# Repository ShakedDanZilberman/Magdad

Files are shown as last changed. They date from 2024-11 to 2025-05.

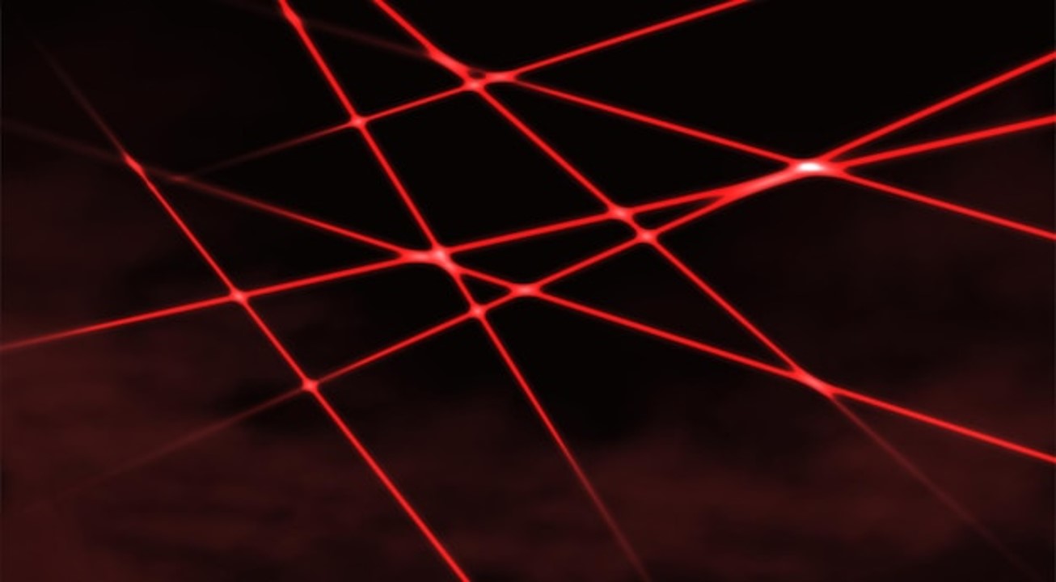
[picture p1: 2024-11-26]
management/requirements presentation/images/lasers.jpg

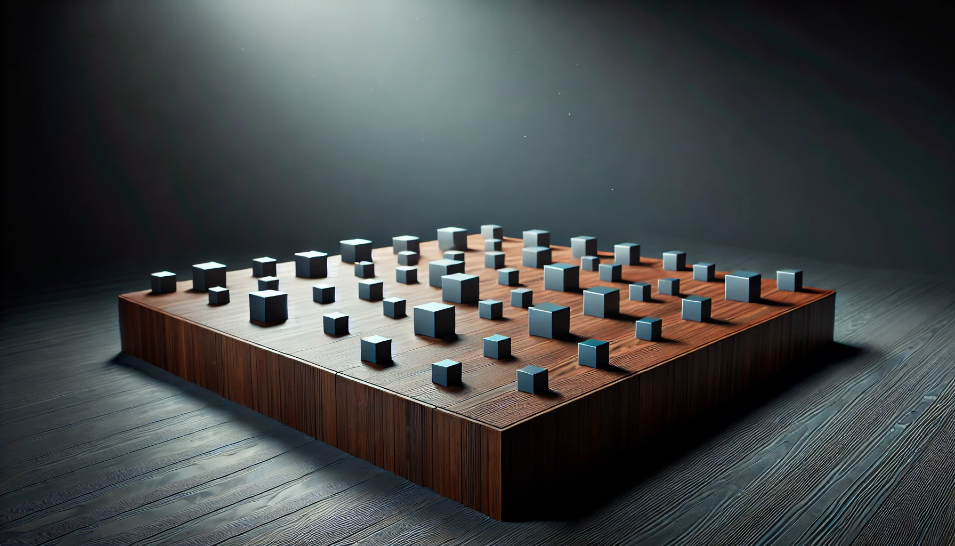
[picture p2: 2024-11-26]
management/requirements presentation/images/dalle image.png

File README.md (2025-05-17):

# Magdad
מגד"ד CounterStrike!
אפשר להגיד שזה מיני רואה יורה בחושך, מיתוג אחר זה לא רואה וכן יורה, יש כאלו שקראו לזה AimBot סטטי בחושך.
המטרה של הפרויקט שלנו היא להדגים יכולת של אחיזה בשטח עם אמצעים מינימליים, כאשר יכולת האש שלנו היא מוגבלת אבל יש הרבה מצלמות, אנחנו יכולים להגן על כל הגזרה בצורה המוצלחת ביותר ועדיין להיות אפקטיביים.

את מטרות אנחנו מזהים בעזרת מודל עיבוד תמונה שנקרא YOLO, לאחר מכן אנחנו משתמשים במנועי סטפר ותותחים שחילצנו מרובי ג'ל.

טבלת שיא כמות לשוניות פתוחות במחשב בנוגע למגדד:
|הערות|כמה|מי|
|---|---|---|
|אני היחיד שרושם?|46|יובל|
| |?|יהלי|
| |?|הוד|
| |?|איילה|
|חכו חכו|5|שקד|

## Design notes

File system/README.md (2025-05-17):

# CounterStrike
## Setup for Starting System (Laser+LIDAR)
1. Connect the 2 USB cables.
2. Open Arduino IDE.
3. Select Board > COM5 > Nano Arduino > OK.
4. File > Examples > Firmata > StandardFirmata.
5. Tools > Processor: "..." > "..." (Old Bootloader) > Upload.
6. Run `system/main.py`.

## To Calibrate the LIDAR Motion
1. Connect the laser pointer and LIDAR to the Arduino, as described above.
2. In `system/fit.py`, uncomment the line `# measure()` in `if __name__ == '__main__':`.
3. Turn off the light, darken the room, fix the system in place.
4. Run `system/fit.py`.
5. **COPY** the output to `system/fit.py` in the `MEASUREMENTS` variable. It will automatically propagate to the rest of the system.

## Errors and Fixes
1. `"pip is not recognized"`
להריץ
`python -m pip install ...`
אם לא עובד לנסות גם:
`py -m pip install ...`
`python3 -m pip install ...`
2. If `torch` fails, uninstall then install again.
3. if you get an error of "getargspec", change to getfullargspec in pyfirmata.

## 2025-05-16
We win.

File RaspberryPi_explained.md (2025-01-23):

## איך עובדים עם RPI בלי כל הכאב ראש ##
 - הRaspBerry PI (RPI) הוא לכל דבר ועניין מחשב קטן, שמריץ מערכת הפעלה מבוססת לינוקס.
 - אנחנו רוצים לכתוב קוד שבסופו של דבר הוא יריץ, מבלי להיות מחוברים אליו עם כבל. לכן אנחנו מתחברים אליו דרך פרוטוקול רשת SSH.
 - כדי להתחבר לRPI דרך הSSH אנחנו  אנחנו נתקין [קליינט SSH בשם PuTTY](https://www.putty.org/), נריץ את PuTTY ובחלון שנפתח נרשום ב Host Name את השם של הRPI שלנו ברשת raspberrypi.local, ונלחץ אנטר.
 - עכשיו אנחנו צריכים להתחבר לאיזשהו חשבון על הRPI:
   - שם משתמש: TeamEthel
   - סיסמה: grauer44 
 - עכשיו אנחנו בטרמינל של הRPI שלנו, יש!
 - אם אנחנו רוצים לראות גם את המסך, נשתמש בפרוטוקול VNC, נתקין [קליינט VNC בשם TigerVNC](https://tigervnc.org/), ובאופן דומה, נתחבר.
 - איך כותבים קוד? אפשר לכתוב ישירות בRPI, אפשר במחשב ואז להעביר קבצים אחד אחד.
 - אפשר לכתוב קוד דרך VS CODE על המחשב האישי בזמן שעורכים את הקבצים בRPI דרך SSH, [בעזרת package שמורידים לVS CODE](https://besomi.com/coding-on-raspberry-pi-remotely-with-visual-studio-code/), [יש גם גרסה לPyCharm](https://medium.com/@sadeepari/access-raspberry-pi-with-ssh-in-pycharm-848df6d31e8a).
 -

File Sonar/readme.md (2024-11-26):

נכון לעכשיו אנחנו משתמשים בסונר מהמעבדה - HC-SR04, הצלחנו לקבל דיוק במרחק של +- 1.5 ס"מ, עם זווית מפתח של 49.4 מעלות (סך הכל).
בתוך זווית הראיה אין יכולת להבדיל בין חבפצים.
עובדים על זה...

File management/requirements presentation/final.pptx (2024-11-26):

## Counter-Strike

- איכון בחושך מוחלט

- חשאיות

- דיוק:
- ±10[cm]

- פגיעה אוטומטית

- תוך
- 1[s]

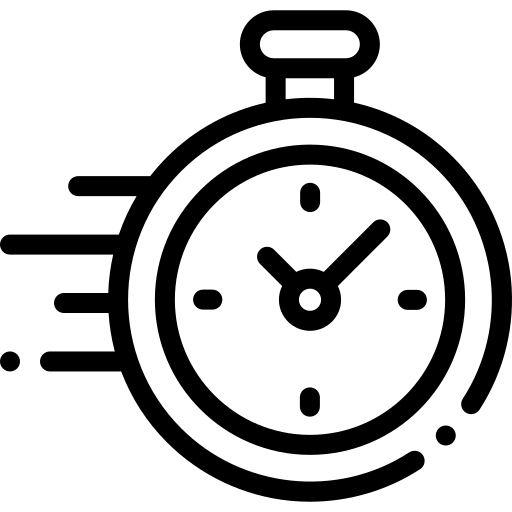
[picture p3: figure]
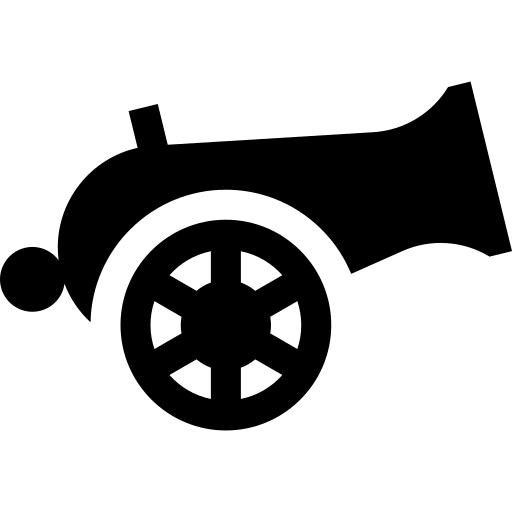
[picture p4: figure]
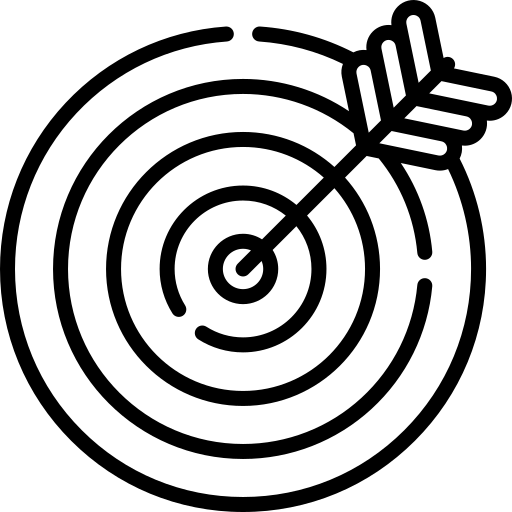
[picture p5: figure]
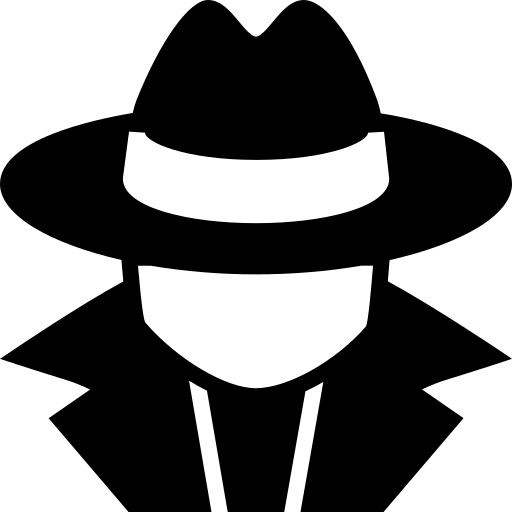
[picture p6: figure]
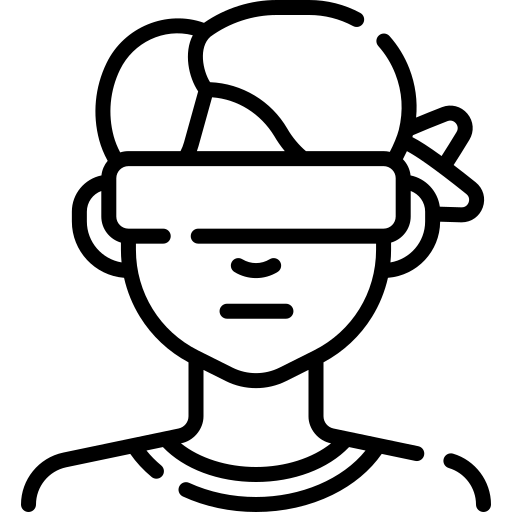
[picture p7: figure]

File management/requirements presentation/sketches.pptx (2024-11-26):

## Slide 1

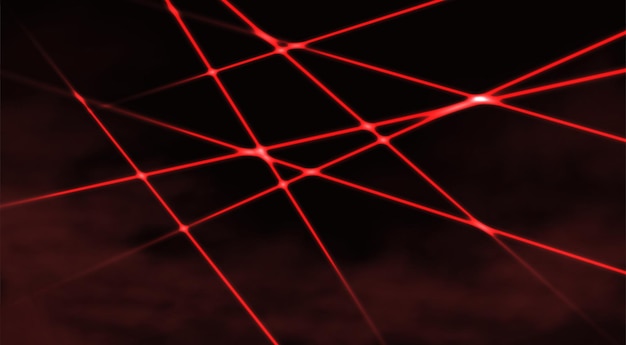
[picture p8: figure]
Red Laser Light Images - Free Download on Freepik
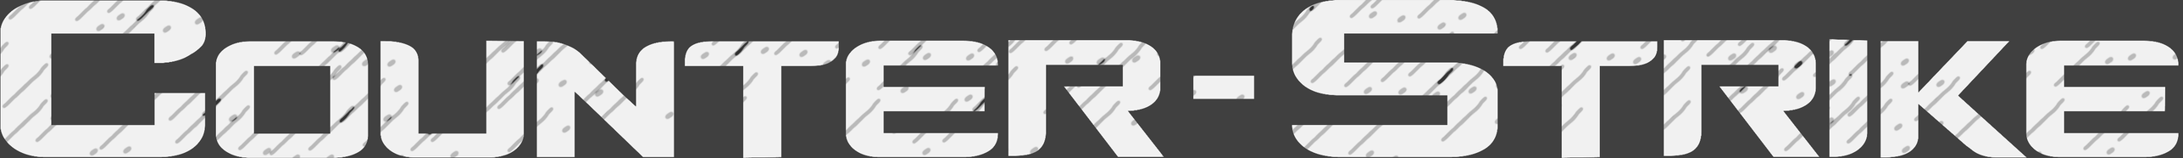
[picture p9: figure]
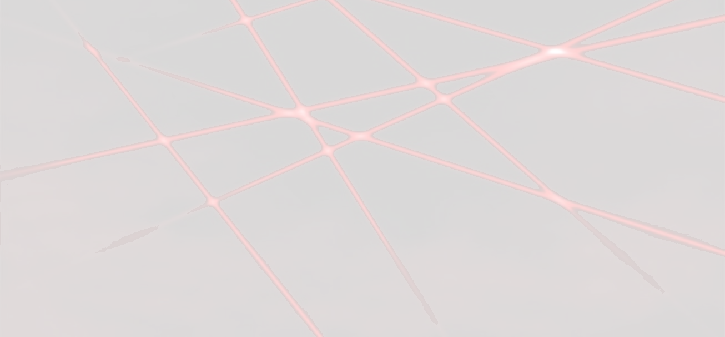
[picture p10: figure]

פגיעה

אוטומטית
תוך 1[s]

איכון

חושך מוחלט
חשאיות
דיוק: 10[cm]±

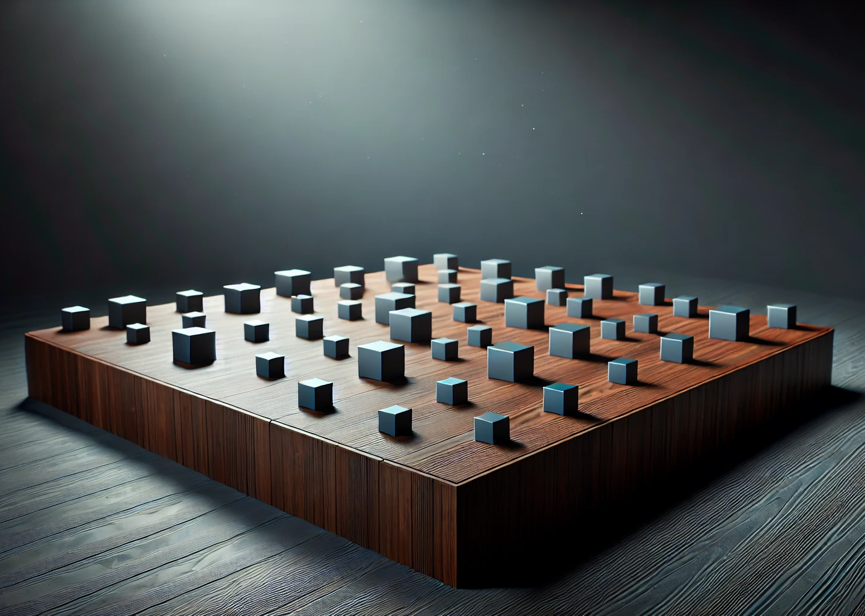
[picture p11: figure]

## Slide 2

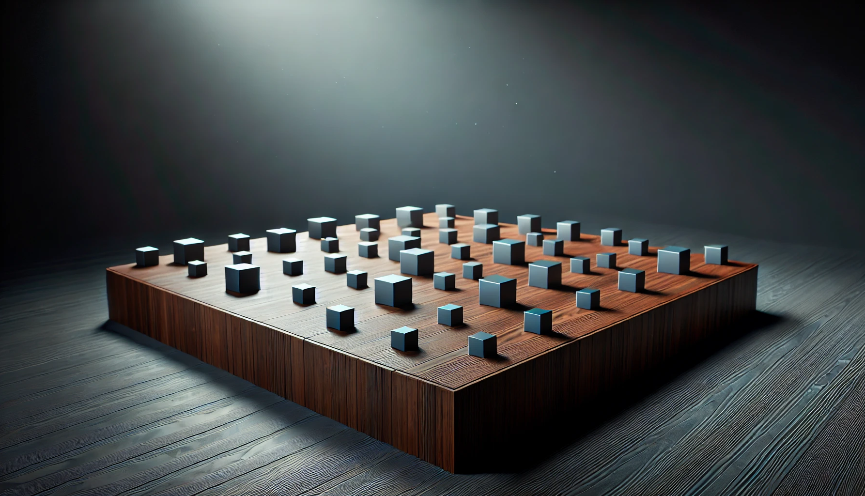
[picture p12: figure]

איכון בחושך מוחלט
חשאיות
דיוק: 10[cm]±

פגיעה אוטומטית
תוך 1[s]

## Counter-Strike

- איכון בחושך מוחלט

- חשאיות

- דיוק:
- ±10[cm]

- פגיעה אוטומטית

- תוך
- 1[s]


## Counter-Strike

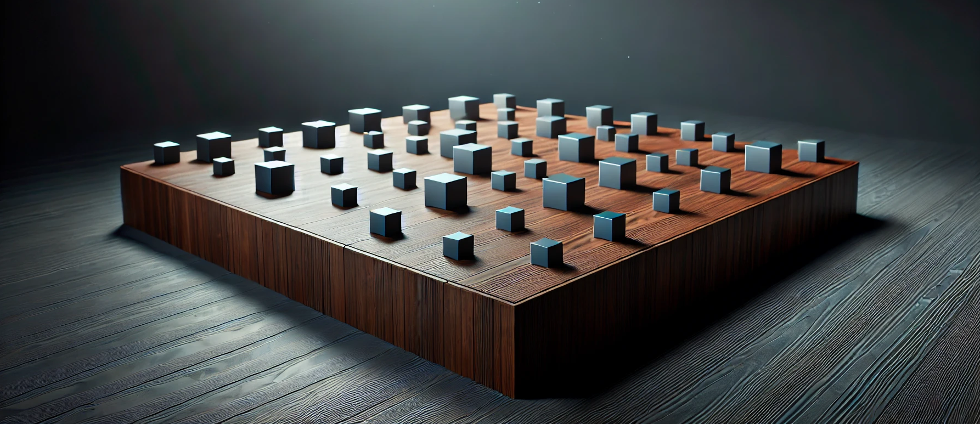
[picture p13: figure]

- תוך
- 1[s]

- פגיעה אוטומטית

- חשאיות

- דיוק:
- ±10[cm]

- איכון בחושך מוחלט

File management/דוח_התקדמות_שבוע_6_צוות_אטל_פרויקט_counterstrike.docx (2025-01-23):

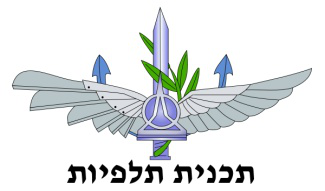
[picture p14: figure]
talpiot

חיל האוויר
ביה"ס לפיקוד ומנהיגות
תכנית תלפיות
‏03 דצמבר 2024
‏ב' כסלו תשפ"ה

סמל יואב סטרוגו, קצין מגד"ד

סמל אייל אפרימה, א' מגד"ד

סמל תומר וקס, א' מגד"ד

סמל אטל גראואר, מפקדת הצוות

צוות אטל

הנדון: דוח התקדמות דו־שבועי – שבוע 6 – צוות אטל - פרויקט CounterStrike

1. יעדים לקראת הצגות רבע:
  1. פיתוח יכולת זיהוי אובייקטים נעים וסטטיים מתוך זרם תמונות תת־אדום.
  2. יכולת "מגן אור" – לֵזִירָה זריזה ומדויקת על נקודה במרחב.
  3. ממשק בין היכולות – זיהוי אובייקט ולזירה עליו, בפחות משנייה.
2. התקדמות:
  1. איכון: חיברנו מצלמה רגילה למחשב עד שמצלמת תת־אדום תגיע ברכש. כרגע, יש כמה שיטות לזיהוי אובייקטים – הפרש תמונות, מציאת Contour־ים. עובדים על לשפר אותן כדי שיהיה זיהוי יציב של עצמים בתמונה. האתגרים העיקריים הם יצירת יציבות בזיהוי וכיול פרמטרים.
  2. ירי: הרכבנו מודול שמסוגל ללזור עם Arduino, מנועים, ודיודת לייזר אדום. לטובת המצלמה שתגיע בהמשך, עוברים ללעבוד עם RaspberryPi דרך SSH שמציב אתגר בהתממשקות עם המודול הפיזי.
  3. אינטגרציה: עוד אין עבודה.
  4. רכש: צפוי שמצלמת התת־אדום תגיע בשבוע 8 או 9.
3. בברכה,

שקד זילברמן, סמל
מהנדס מערכת

- בלמ"ס - בלמ"ס 2

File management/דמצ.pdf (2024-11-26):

בלמ"ס
1

בלמ"ס

- בלמ"ס -

חיל האוויר
ביה"ס לפיקוד
ומנהיגות
תכנית תלפיות
15 נובמבר 2024
י"ד חשון תשפ"ה

הנדון: דרישה מבצעית לפרוייקט מגדל דוד- CounterStrike .1 צורך מבצעי
א. לאויב יש תותחים אשר משגרים עלינו רקטות. אנו רוצים לפגוע בתותחים הללו לפני שהם יורים עלינו. אין לנו מידע מודיעיני על צורתם אך יודעים שהם חייבים להיות בגודל מינימלי של כדור בקוטר [c].6 התותחים נייחים אך האויב יודע להעלות אותם לפני האדמה שניות ספורות לפני השיגור וברוב הזמן הם נמצאים בתת קרקע ולא ניתנים לאיכון. המטרה היא לאכן אותם ולהספיק לפגוע בהם לפני שמשוגר מהם טיל. שימו לב שחלק נרחב מהירי מתבצע בשעות החשכה. בפתרון
זה נתמקד בזירה שפני השטח שלה מישוריים וחוץ מהתותחים לא נמצא בה דבר. בנוסף, אנו רוצים שפלטפורמת האיכון שלנו תהיה חשאית¹ כדי שמירוץ הלמידה של האויב יהיה קשה יותר.
ב. איכון – זיהוי מיקום מדויק, כלומר מתן קורדיאנטות מדויקות למיקומו של הגוף )יכול להיות מרחק וזווית או כל סוג אחר של קורדינאטות(. בשלב זה הצפייה היא לאיכון במישור ולא במרחב.
.2 אילוצי הפתרון
א. הפתרון חייב לעמוד בתקציב של 2000 שקלים. ב. על מנת לא לבזבז סד"כ מיירטים נרצה שירי על מטרות שווא יהיה מצומצם ככל הניתן ושאחוזי הפגיעה יהיו גבוהים ככל הניתן ועל שני הפרמטרים הללו המערכת תימדד. .3 דרישות:
א. איכון :
- על המערכת להציג את הסריקות על גבי מסך ולסמן את האיכונים של המטרות עם שיערוך של מרכז הגוף בוודאות של 50% ו90%-
- הדיוק של מערכת האיכון אמור להיות [c]±10
- כושר ההפרדה בין גופים אמור להיות [c]3 )כלומר אם קצות הגופים נמצאים לכל הפחות 3 סנטימטרים זה מזה הגופים אמורים להיות מקוטלגים כמטרות שונות( ב. פגיעה במטרה:
- לאחר איתור המטרה יש לבצע ירי אליה ופגיעה בה - מטרה בקוטר [c]6 לפחות.
- על הפגיעה להיות אוטומטית לאחר האיכון
- פגיעה תוך []1 מרגע עליית המטרה לפני השטח .4 צירי עומק:
א. איכון תלת מימדי:
- בזירות שונות שעלינו להתמודד איתן פני השטח אינם מישוריים ולכן יש צורך באיכון מטרות במרחב ולא במישור. ב. התמודדות עם מטרה נעה )על מנת לבצע פגיעה יש צורך לבצע מעקב וחיזוי(:

1
חשאית – בעלת חתימה ספקטרלית כמובן, אך לא נשמעת במובהק ולא נראית במובהק.

בלמ"ס
2

בלמ"ס

- בלמ"ס -
- חלק מהתותחים ניידים – ז"א נוסעים על משאיות במהירות קבועה עד למיקום החדש- נרצה לפגוע בהם בזמן הנסיעה.
- לעיתים אנו מחטיאים את מטרת התותח אך אסור שהטילים )המודיעין אומר שמדובר
בנשק סטטיסטי ובליסטי( יפגעו בתושבים, תחת הנחה מקלה שהטילים בגודל של
מטרה מינימלית – עלינו לפגוע בטיל. ג. התמודדות עם ל"א - האויב יודע ולומד את מערכות ההגנה שלנו ומצא את תדר השידור:
- התמודדות עם הימצאות גוף משדר באותם תדרים, באותו תווך, ובטווח הרלוונטי
שלומד אותנו ומשכלל את היכולות שלו.
ד. אינטגרציה של מספר מערכות ויצירת מרחב חכם:
- מספר מאכנים / מספר מערכות פגיעה
- תקשורת
ה. המודיעין הביא מידע שתותחים לטווחים שונים עשויים מחומרים שונים ולכן ידיעת החומר תיתן לנו מידע על המטרה בניסיון ללמוד את האויב:
- אלגוריתמיקה לזיהוי חומרים שונים במובהק )ספוג, מתכת, נייר, זכוכית וכד'( .5 פרטי הלקוח
פרוייקט פנימי- תחת סרן שיר סגמן

.6 בברכה,

אטל גראואר, סמל
מפקדת צוות

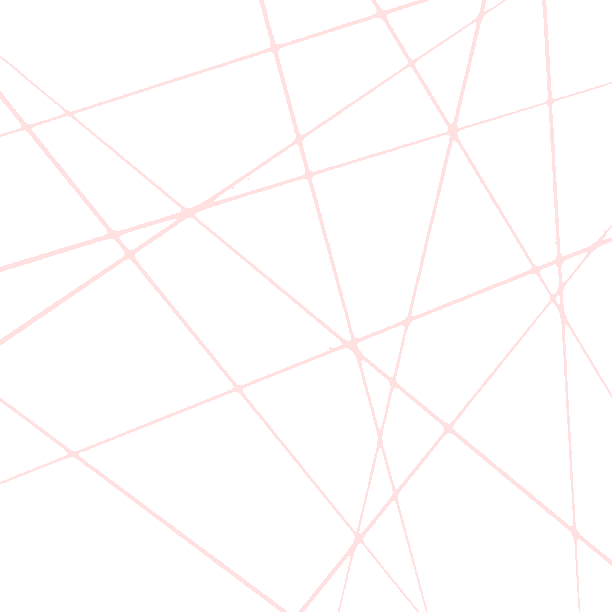
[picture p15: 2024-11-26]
management/requirements presentation/images/lasers2.png

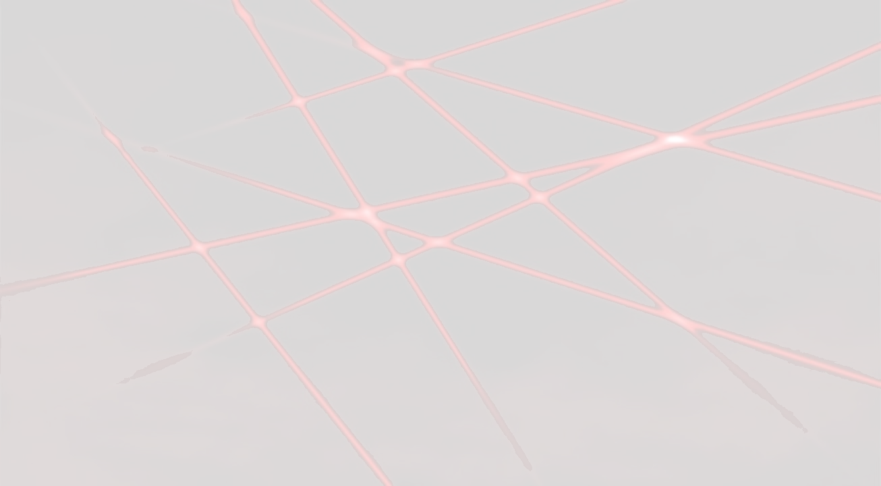
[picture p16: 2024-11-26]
management/requirements presentation/images/lasers.png

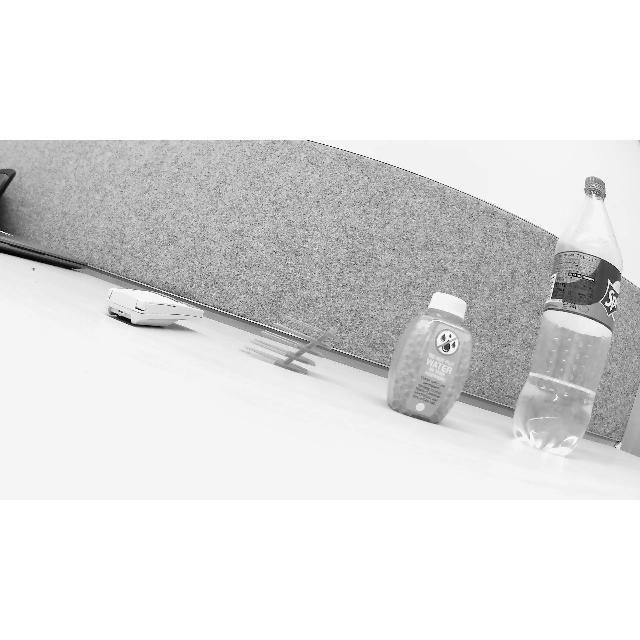
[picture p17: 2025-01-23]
camera-training-2/train/images/WIN_20250113_22_37_09_Pro_jpg.rf.8b2d5ae4b71cfda3e93c12469997346b.jpg

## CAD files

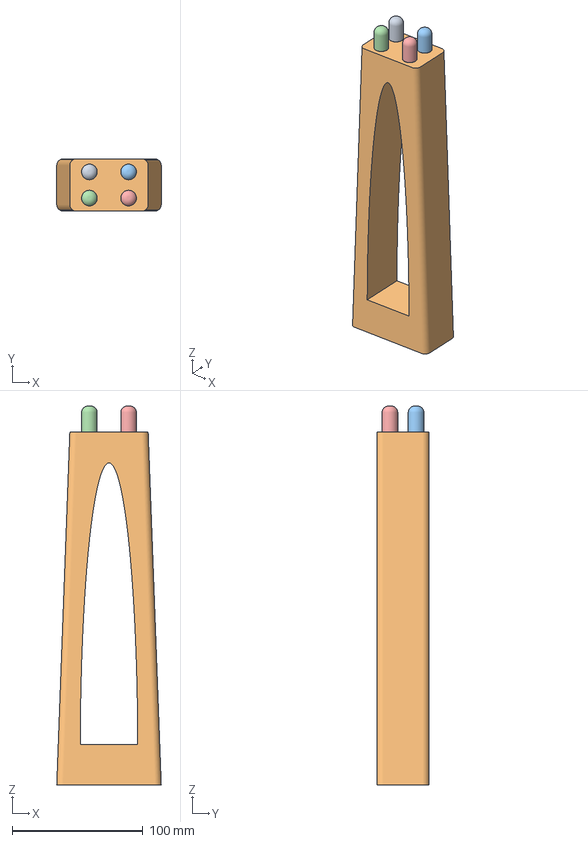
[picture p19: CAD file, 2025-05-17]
3D print/Camera Stand/lowerpart_scaled_stl.3mf
80.0 x 40.0 x 290.0 mm

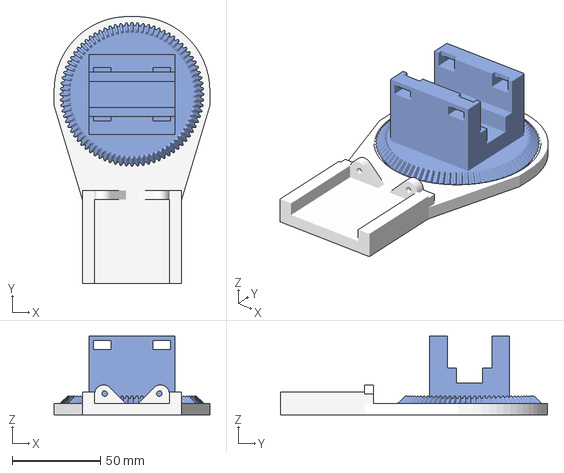
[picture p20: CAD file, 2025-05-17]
3D print/full_module/Part Studio 1.3mf
88.2 x 151.2 x 44.6 mm
base gear
base

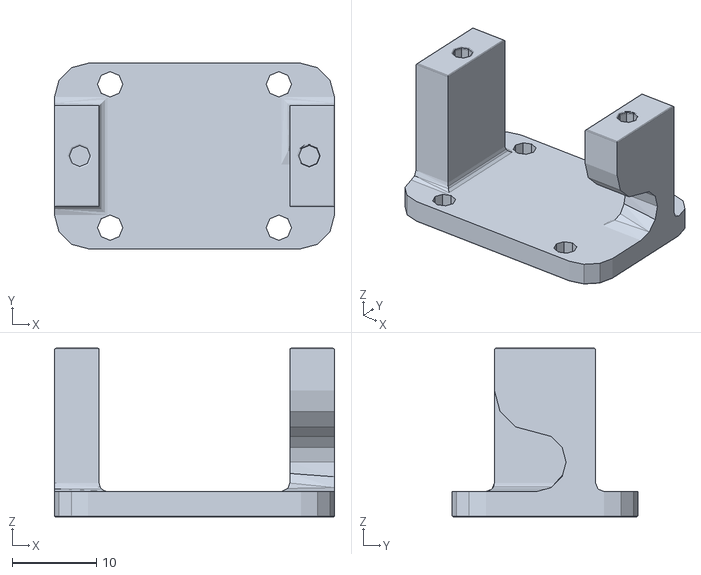
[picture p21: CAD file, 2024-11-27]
3D print/Laser_gun_bracket/laser-gun-bottom-bracket.stl
33.2 x 22.0 x 20.0

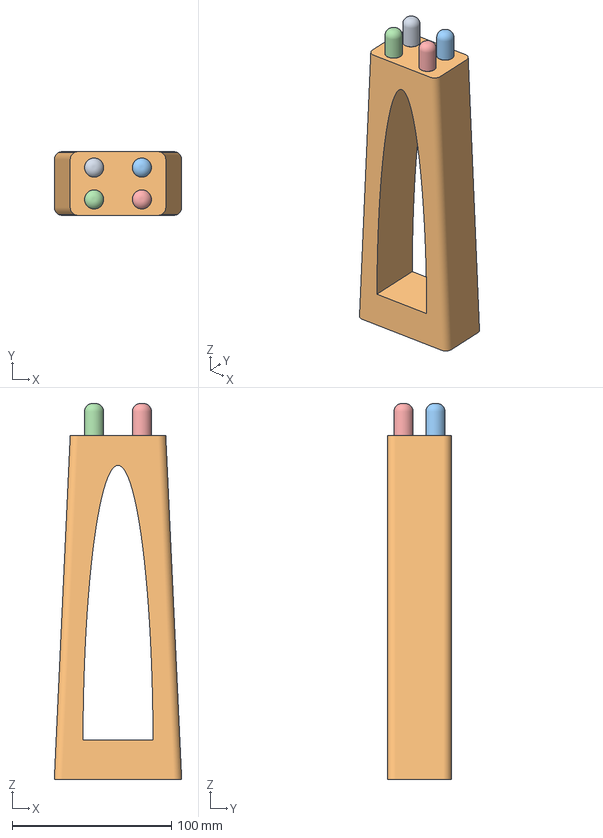
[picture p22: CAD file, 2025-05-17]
3D print/Camera Stand/lowerpart_x160.3mf
80.0 x 40.0 x 236.0 mm

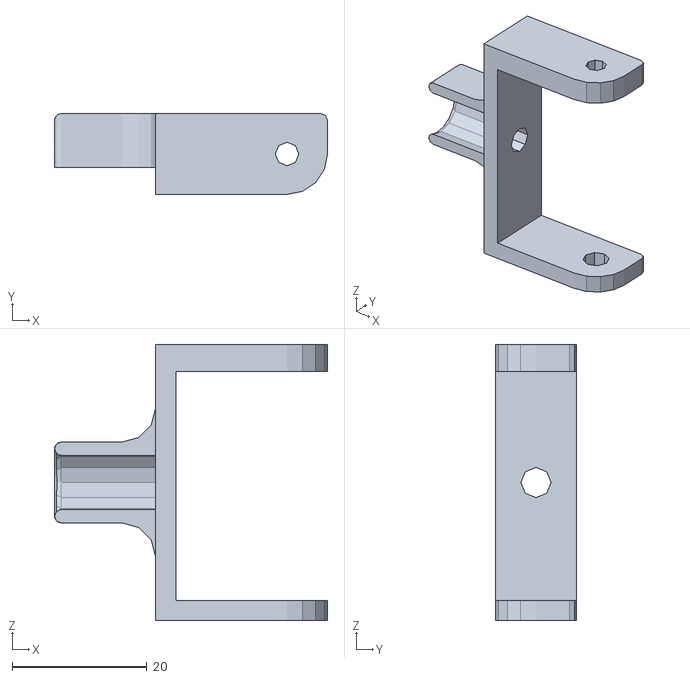
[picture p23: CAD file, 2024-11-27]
3D print/Laser_gun_bracket/laser-gun-top-bracket.stl
40.5 x 12.0 x 41.0

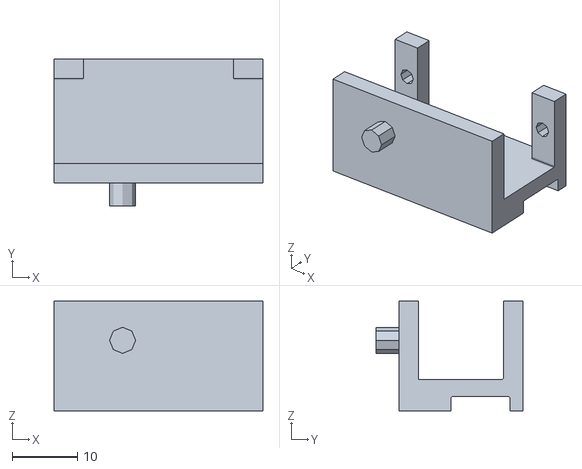
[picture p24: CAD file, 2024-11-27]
3D print/Laser_gun_bracket/laser-gun-middle-bracket.stl
32.0 x 22.5 x 16.8

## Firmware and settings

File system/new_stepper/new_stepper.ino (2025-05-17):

#include <AccelStepper.h>

/*
CNC pins Z - 
const int gunPin = 12;
const int dirPin = 4;
const int stepPin = 7;
const int enablePin = 8;



bodoboard - 
const int gunPin = 4;
const int dirPin = 3;
const int stepPin = 2;
const int enablePin = 5;
*/

const int gunPin = 12;
const int dirPin = 4;
const int stepPin = 7;
const int enablePin = 8;
const int SHOOT_COOLDOWN = 4;  // ms
const int MAX_SPEED = 3000;  // steps per second
const int ACCELERATION = 10000;  // steps per second^2
float count = 0;

// Stepper setup: DRIVER interface type = 1
AccelStepper stepper(AccelStepper::DRIVER, stepPin, dirPin);

int mistake()
{
  if (count>1)
  { 
    count-=1;
    return 1;
  }
  else if(count<-1)
  {   
    count+=1;
    return -1;
  }
  return 0;
}
void setup() {
  Serial.begin(9600);
  pinMode(gunPin, OUTPUT);
  pinMode(enablePin, OUTPUT);

  stepper.setEnablePin(enablePin);
  // stepper.enableOutputs();
  stepper.setPinsInverted(false, false, true);
  stepper.disableOutputs();

  // Stepper setup
  stepper.setMaxSpeed(MAX_SPEED);        
  stepper.setAcceleration(ACCELERATION);     
  stepper.setCurrentPosition(0);    // reset position
}

long angle_to_steps(double angle){
  // each step is 1.8 deg
  // steps = angles / 1.8
  // we have a 2 : 1 ratio in the wheels
  // the gears change the direction, we want + to be to the right
  // the lib agrees, positive is clockwise,
  // meaning we need to multiply by -2
  // and then round to the nearest int.
  // TODO: understand why different?>??????>?>??DF&^O*HOJP
  // Black gun = *4
  // White gun = *2
  return long(-4 * angle / 1.8);
}

void loop() {
  if (Serial.available()) {
    String command = Serial.readStringUntil('\n');
    command.trim();

    if (command == "SHOOT") {
      digitalWrite(gunPin, HIGH);
      Serial.println("Pew Pew");
      delay(SHOOT_COOLDOWN);
      digitalWrite(gunPin, LOW);
      Serial.println("Done"); // Critical for communication with Python
    } 
    else if (command.startsWith("ROTATE:")) {
      stepper.enableOutputs();
      long steps = command.substring(7).toInt();
      float step = command.substring(7).toFloat();
      count +=step-float(steps);
      Serial.print("Requested steps: ");
      Serial.println(steps);
      Serial.println(step);
      long angle = angle_to_steps(steps);
      float mis=mistake();
      Serial.println(mis);
      stepper.move(angle+mis); 
      Serial.println("Done"); // Critical for communication with Python
    }else if (command.startsWith("ANGLE:")) {
      stepper.enableOutputs();
      double angle = command.substring(6).toDouble();
      long steps = angle_to_steps(angle);
      Serial.print("Requested steps: ");
      Serial.print(steps);
      Serial.print("   with an angle of: ");
      Serial.println(angle);
      stepper.move(steps);
      Serial.println("Done"); // Critical for communication with Python
    }else if(command =="OFF"){
      stepper.disableOutputs();
      Serial.println("Turned off.");
    }else if(command =="ON"){
      stepper.enableOutputs();
      Serial.println("Turned on.");
    }
  }
  if (stepper.currentPosition() == stepper.targetPosition()){
    stepper.disableOutputs();
  }
  stepper.run();
}

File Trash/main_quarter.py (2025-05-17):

# Get all connected devices

import time
import cv2
import numpy as np
import matplotlib.pyplot as plt
from abc import ABC, abstractmethod
from pyfirmata import Arduino, util
import threading
from queue import Queue
CAMERA_INDEX_0 = 1
MAX_CAMERAS = 10
timestep = 0
centers = [[90, 90]]
# Parameters to play with in calibration
INITIAL_BLURRING_KERNEL = (3, 3)
EDGE_DETECTION_MINTHRESH = 150
EDGE_DETECTION_MAXTHRESH = 180

HIGH_CEP_INDEX = 0.9
LOW_CEP_INDEX = 0.5
DILATION_ITERATIONS = 2
EROSION_ITERATIONS = 2


DILATION_KERNEL = (5, 5)
OPENING_KERNEL = (5, 5)
CLOSING_KERNEL = (3, 3)
EROSION_KERNEL = (3, 3)


CONTOUR_EXTRACTION_M0DE = cv2.RETR_EXTERNAL
CONTOUR_EXTRACTION_METHOD = cv2.CHAIN_APPROX_SIMPLE
CONTOUR_THICKNESS = cv2.FILLED
CONTOUR_HEATMAP_BLUR_KERNEL = (15, 15)
CONTOUR_HEATMAP_STDEV = 15

DIFF_THRESH = 0
INITIAL_CONTOUR_EXTRACT_FRAME_NUM = 30
CHECK_FOR_NEW_OBJECTS = 12

IMG_WIDTH = 240
IMG_HEIGHT = 320


class Handler(ABC):
    @abstractmethod
    def add(self, img):
        pass

    @abstractmethod
    def get(self):
        pass

    @abstractmethod
    def display(self):
        pass

    @abstractmethod
    def clear(self):
        pass


class ContoursHandler(Handler):
    def __init__(self):
        self.static = None

    def optimize_edges(self, edges):
        # TODO: ADD DOCSTRING
        dilation_kernel = np.ones(DILATION_KERNEL, np.uint8)
        opening_kernel = np.ones(OPENING_KERNEL, np.uint8)
        closing_kernel = np.ones(CLOSING_KERNEL, np.uint8)
        erosion_kernel = np.ones(EROSION_KERNEL, np.uint8)
        dilated_edges = cv2.dilate(
            edges, dilation_kernel, iterations=1
        )
        opening = cv2.morphologyEx(dilated_edges, cv2.MORPH_OPEN, opening_kernel)
        closing = cv2.morphologyEx(opening, cv2.MORPH_CLOSE, closing_kernel)
        erode = cv2.erode(closing, erosion_kernel, iterations=EROSION_ITERATIONS)
        # cv2.imshow("edges", edges)
        # cv2.imshow("dilation", dilated_edges)
        # cv2.imshow("opening", opening)
        # cv2.imshow("closing", closing)
        # cv2.imshow("erode", erode)
        return erode

    def add(self, img):
        erosion_kernel = np.ones(EROSION_KERNEL, np.uint8)
        dilation_kernel = np.ones(DILATION_KERNEL, np.uint8)

        gray = ImageParse.toGrayscale(img)
        height, width = img.shape
        black_canvas = np.zeros((height, width, 3), dtype=np.uint8)
        # manipluate the image to get the contours
        blurred = cv2.GaussianBlur(gray, INITIAL_BLURRING_KERNEL, 0)
        edges = cv2.Canny(blurred, EDGE_DETECTION_MINTHRESH, EDGE_DETECTION_MAXTHRESH)
        optimized = self.optimize_edges(edges)
        contours, hierarchy = cv2.findContours(
            optimized, CONTOUR_EXTRACTION_M0DE, CONTOUR_EXTRACTION_METHOD
        )
        cv2.drawContours(black_canvas, contours, -1, (255, 255, 255), CONTOUR_THICKNESS)
        black_canvas = cv2.erode(black_canvas, erosion_kernel, iterations=EROSION_ITERATIONS)
        black_canvas = cv2.dilate(black_canvas, dilation_kernel, iterations=DILATION_ITERATIONS)
        binary_heat_map = ImageParse.toGrayscale(black_canvas)
        # heat_map = cv2.GaussianBlur(black_canvas, CONTOUR_HEATMAP_BLUR_KERNEL, CONTOUR_HEATMAP_STDEV)
        self.static = binary_heat_map

    def display(self, img):
        TITLE = "Contours"
        if self.static is None:
            return
        cv2.imshow(TITLE, self.static)

    def clear(self):
        pass

    def get(self):
        return self.static


class Accumulator:
    """
    Accumulator class to accumulate B&W heatmaps
    It adds images with a weight of 0.1 to the accumulator

    add(img) - adds the image to the accumulator
    clear() - clears the accumulator
    get() - returns the accumulator image
    """
    LOOKBACK = 10

    def __init__(self):
        self.accumulator = None
        self.window = []

    def add(self, img, prev_weight, new_weight):
        if not isinstance(img, np.ndarray):
            return
        if len(img.shape) < 2:
            return
        if self.accumulator is None:
            self.accumulator = np.zeros((img.shape[0], img.shape[1]), dtype=np.uint8)
        self.window.append(img)
        if len(self.window) > Accumulator.LOOKBACK:
            self.window.pop(0)
        moving_average = np.zeros((img.shape[0], img.shape[1]), dtype=np.uint8)
        for frame in self.window:
            moving_average += (frame * 0.3).astype(np.uint8)
        moving_average = np.clip(moving_average, 0, 255)
        moving_average = moving_average.astype(np.uint8)
        self.accumulator = moving_average

    # def add_static(self, img, number_of_frames_so_far):
    #     if self.accumulator is None:
    #         self.accumulator = np.zeros((img.shape[0], img.shape[1]), dtype=np.uint8)
    #     self.accumulator = cv2.addWeighted(self.accumulator, 1-1/number_of_frames_so_far, img, 1/number_of_frames_so_far, 0)

    def clear(self, img):
        self.accumulator = np.zeros((img.shape[0], img.shape[1]), dtype=np.uint8)
        self.window = []

    def get(self):
        return self.accumulator


class RawHandler(Handler):
    """
    RawHandler class to present the raw image from the camera.
    It does not manipulate the image in any way.

    add(img) - adds the image to the handler
    clear() - clears the image
    get() - returns the image
    display() - displays the image
    """

    TITLE = "Camera Connection"

    def __init__(self):
        self.img = None

    def add(self, img):
        self.img = img

    def get(self):
        return self.img

    def display(self):
        if self.img is None:
            return
        cv2.imshow(RawHandler.TITLE, self.img)

    def clear(self):
        self.img = None
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

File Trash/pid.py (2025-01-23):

import time
import numpy as np


class PID:
    """
    PID controller for general use.
    Currently redundant, but can be used for future implementations.
    """
    def __init__(self, Kp=0.1, Ki=0.1, Kd=0):
        """
        Initialize PID controller

        Initializes the PID controller with the previous time, integral and error values set to 0
        """
        # PID constants
        self.Kp = Kp
        self.Ki = Ki
        self.Kd = Kd

        # Initialize previous values for PID
        self.time_prev = time.time() / 100
        self.integral = 0
        self.error_prev = 0

    def set_constants(self, new_Kp, new_Ki, new_Kd):
        """
        Set new PID constants

        Args:
            new_Kp (float): new Proportional constant
            new_Ki (float): new Integral constant
            new_Kd (float): new Derivative constant
        """
        self.Kp = new_Kp
        self.Ki = new_Ki
        self.Kd = new_Kd
        return

    def PID(self, target: tuple[float, float], curr: tuple[float, float]):
        """
        PID controller for the system, returns the angle to turn to reach the target position

        Args:
            target (tuple[float, float]): target position to reach
            curr (tuple[float, float]): current position of the system

        Returns:
            float: angle to turn to reach the target position
        """
        # target and curr are (x, y)
        now = time.time() / 100
        error = target - curr

        P = self.Kp * error
        I = self.integral + self.Ki * error * (now - self.time_prev)
        D = self.Kd * (error - self.error_prev) / (now - self.time_prev)

        self.error_prev = error
        self.time_prev = now
        
        return np.sum(np.nan_to_num([P, I, D]))

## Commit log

2024-11-26 Upload requirements presentation
    הצגת דמצ
2024-11-26 סקריפט פשוט לקריאה מסונאר אחד שלא זז
2024-11-27 סדר בתיקיות פרויקט
    העלתי את הקבצים של הדפסת תלת מימד בשביל מודול ירי וסידרתי את הבלאגן של יובל בר בתיקית ראדאר (העברתי לסונר)
    [laser-gun-bottom-bracket.stl, laser-gun-middle-bracket.stl, laser-gun-top-bracket.stl]
2024-11-27 קוד לרובה לייזר
    קוד מיוטיוב, משהו משהו
2024-11-27 שינוי קטן
2024-12-02 Connected the camera feed
2024-12-02 Added ability to check for working cameras
2024-12-02 Camera Experiments
    i tried to mess with opencv and understand how it works. baby steps
2024-12-02 קוד לזיהוי קצוות + קוד לזיהוי אובייקטים
2024-12-03 Ability to recognise deltas from first frames
2024-12-03 עדכונים
    פונקציה שמאתחלת מערכת לפי סימון של המשתמש איפה האזור הרלוונטי לזיהוי אובייקטים, פונקציה שמזהה אובייקטים בהינתן מסכה של מקומות רלוונטים. (מניח שהמצלמה סטטית.)
2024-12-03 עדכונים מרגשים!!!
    הצלחנו לשפר ממש את הפונקציה שמזהה אובייקטים
2024-12-03 עדכונים יפים
    שיפרנו עוד קצת
2024-12-10 הורדתי אתחול של הלוח
    בקובץ camera_experiments1 הורדתי את הקטע המעצבן שצריך כל פעם לסמן מה הלוח, נחזיר כשיהיה צורך(:
2024-12-10 לייזר פייטון
    קוד לארדואינו דרך פייטון
2024-12-10 PID UPDATE
    הוספתי מערך PID
2024-12-10 trig works, PID sucks. added a little bit of comments
2024-12-11 שינוייםםםם
2024-12-11 added PID, works, needs tuning
2024-12-11 הוספתי מחלקה של קבלת החלטות
2024-12-15 שיניתי את המספרי פינים לדבר הנכון
2024-12-15 סרטון לטסטסים של עיבוד תמונה - סטטי יחסית
2024-12-15 כיול לייזר
2024-12-15 עדכון פרמטרי התאמה
2024-12-15 moved raspberry_test.py
2024-12-15 קובץ לייזר חדש שלוזר אוטומטית
2024-12-15 working pid
2024-12-15 PID and calib connected, almost good, very spaghetti
2024-12-17 added print
2024-12-17 סידור קוד
2024-12-23 Integrated laser code into image parsing
2024-12-25 כיול
2024-12-25 כיול 2
2024-12-25 שינוייםםם השעה היא 13:32
2024-12-25 משהו
    [fit_parameters.txt]
2024-12-25 לזירה?
2024-12-25 working prototype
2024-12-31 remove unnecessary files
    [fit_parameters.txt]
2024-12-31 create a class for PID
2024-12-31 moved pid to class
2024-12-31 move code from calibration.py
2024-12-31 מדד מרחק
    פונקציה שמודדת מרחק עם לידאר
2024-12-31 add print statement
2024-12-31 If fails to connect to arduino, print mode
    [laser.py]
2025-01-01 לידאר
2025-01-01 Create LidarPin in laser.py
2025-01-01 מדידת מרחק באמצעות lidar
    in the function laser_thread there is a print of distance. הכיול לא עובד
2025-01-01 שינוי
    עכשיו זה גם מכויל
2025-01-05 כיול תקף
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2025-01-06 Functioning version
    1) Calibration is off
    2) Clicking too far from the centre of the image results in a ValueError exception. Probably something with the angles overflowing, going to debug.
2025-01-06 Fixed bug from previous commit with bounding
    [laser.py]
2025-01-06 fix find_red_point, added GUI
    [fit.py]
2025-01-09 fix the weighting in bilerp
    [fit.py]
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2025-01-20 moved CAMERA_INDEX to constants.py
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2025-01-20 Working just_changes_main (upto calibration)
2025-01-21 almost everything is working
    todo:
    1. figure out shooting
    2. calibrate gun position
    3. adjust contour parameters to scene
2025-01-21 Refactor measurement data structure and update voltage handling in gun control
2025-01-22 committing for calibration initial
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2025-01-22 Enhance Gun initialization with optional print flag and add placeholder for shoot_target method
2025-01-22 Fix PID calculation and improve gun control logic; handle None motor voltage and simplify error handling
    [gun.py, main.py, pid.py]
2025-01-22 Important -- correct image size
    [constants.py]
2025-01-22 הכנסתי את המודל המאומן לתיקיה של מגדד
2025-01-23 move YOLO code to SAMPLE_RATE
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2025-01-23 Improve Arduino connection handling in Gun and LaserPointer classes
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2025-03-26 תיקון nonetype error
2025-03-28 Add initial Jupyter notebook for testing Gun and LaserPointer functionality
2025-03-31 information about the stepper
2025-03-31 Code that works for the motor
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2025-04-07 Add stepper motor control code and example usage in Jupyter notebook
2025-04-07 Refactor camera handling and add global target management for multi-camera setup
2025-04-21 trying to fix homography
    [cameraIO.py, constants.py, image_processing.py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]
2025-04-21 Add stepper control functionality and example usage in Jupyter notebook
2025-04-21 Working version of Gun
    Notice the stepper.ino file that must run
2025-04-21 Update stepper.ino
    Very important code that was abandoned on the main branch
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2025-04-21 Update yuvaltest.ipynb
    אינטגרציה של הומוגרפיה והמנוע החדש
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2025-04-28 remove pid, working gun!
2025-04-28 brain גרסה טיפשה יחסית שעובדת
2025-04-28 Create Part Studio 1.3mf
    [Part Studio 1.3mf]
2025-04-28 new main!
    run_game עובד עם קצת באגים, במחלקה של המוח
2025-04-29 test yolo clean creation
    ושינוי שורה אחת בcameraIO
2025-04-29 הוספנו בדיקה פשוטה שמצלמה עובדת
2025-04-29 העברתי מלא דברים לטראש
2025-04-29 faster yolo
    made images smaller so processing is easier. havent resolved exporting the model to better format
    [yolo.py]
2025-05-05 שינויים
    מטריצת הומוגרפיה נכנסת באתחול, שינויים של יהלי שעובד על דיספליי בהערה
2025-05-05 שינויים מרגשים רצחחחחח
    כתבתי עוד מיין שנקרא game_loop_independent והמטרה שלו היא שנוכל לבחון את הflow בלי yolo
2025-05-09 לטססס גוווו סטפר עובדים (נראה לי)
2025-05-09 Refactored printing in gun.py
2025-05-09 and corrected gun.py main
    [gun.py]
2025-05-11 3d models
    [lowerpart_scaled_stl.3mf, lowerpart_x160.3mf]
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2025-05-14 display thread on the way
2025-05-14 fixing cameras halfway
2025-05-14 נתק אותי Co-authored-by: YahliMB <YahliMB@users.noreply.github.com>
2025-05-14 cleared printing and added import defence
2025-05-14 replaced pins for the new board
    [stepper.ino]
2025-05-14 removed prints and global
2025-05-14 cameraIO updates & homography
2025-05-14 Revert "Merge branch 'yolo-integration' of https://github.com/ShakedDanZilberman/Magdad into yolo-integration"
    This reverts commit f727cceb3a92b41285457e8e9d0e4357687dbef2, reversing
    changes made to 421cb693c5585e61dbc5cdb7e23f57b28a53c455.
    [Brain.py, constants.py, eyefile.py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]
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2025-05-15 יובל ושקד מסדרים שיט
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
